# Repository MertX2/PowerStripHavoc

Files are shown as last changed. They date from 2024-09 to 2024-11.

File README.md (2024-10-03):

# PowerStripHavoc
PowerStripHavoc is a WIP power regulation PCB for Wii Portables that sits on top of the Wii mainboard and inbetween the CPU and GPU. It is heavily inspired by YveltalGriffin's [Thundervolt](https://github.com/mackieks/thundervolt) , loopj's [short stack](https://github.com/loopj/short-stack) project and different PCBs, and the [RVL-PMS](https://github.com/Gmanmodz/RVL-Power-Management-System) by gmanmodz. 

Its name is a combination of loopj's PowerStrip, which is the base of this project, and the Havoc weapon from Apex Legends. 

This Project is currently in the testing phases and is in no way ready to be used.




# Firmware
The firmware is written in Cpp using the Arduino Framework via [megaTinyCore](https://github.com/SpenceKonde/megaTinyCore) .
In order to compile it, you just need VSCode with the PlatformIO addon installed.

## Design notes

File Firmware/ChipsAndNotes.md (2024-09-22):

- IP2721 ODER CH224K
- CH224K Example Project https://hackaday.io/project/194207-usb-power-delivery-decoy-ch224k
- BQ driver, 2 Versionen, Spencer ist original, Ratti ist ein Fork für den BQ25896
- BQ driver selber implementieren SOLLTE einfach sein
- Evtl. RVLOADER pms spoofing???

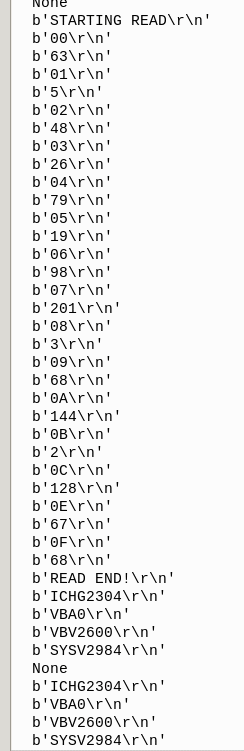
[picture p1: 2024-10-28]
Firmware/SerialRead_html_a3b800cb49ea278a.gif

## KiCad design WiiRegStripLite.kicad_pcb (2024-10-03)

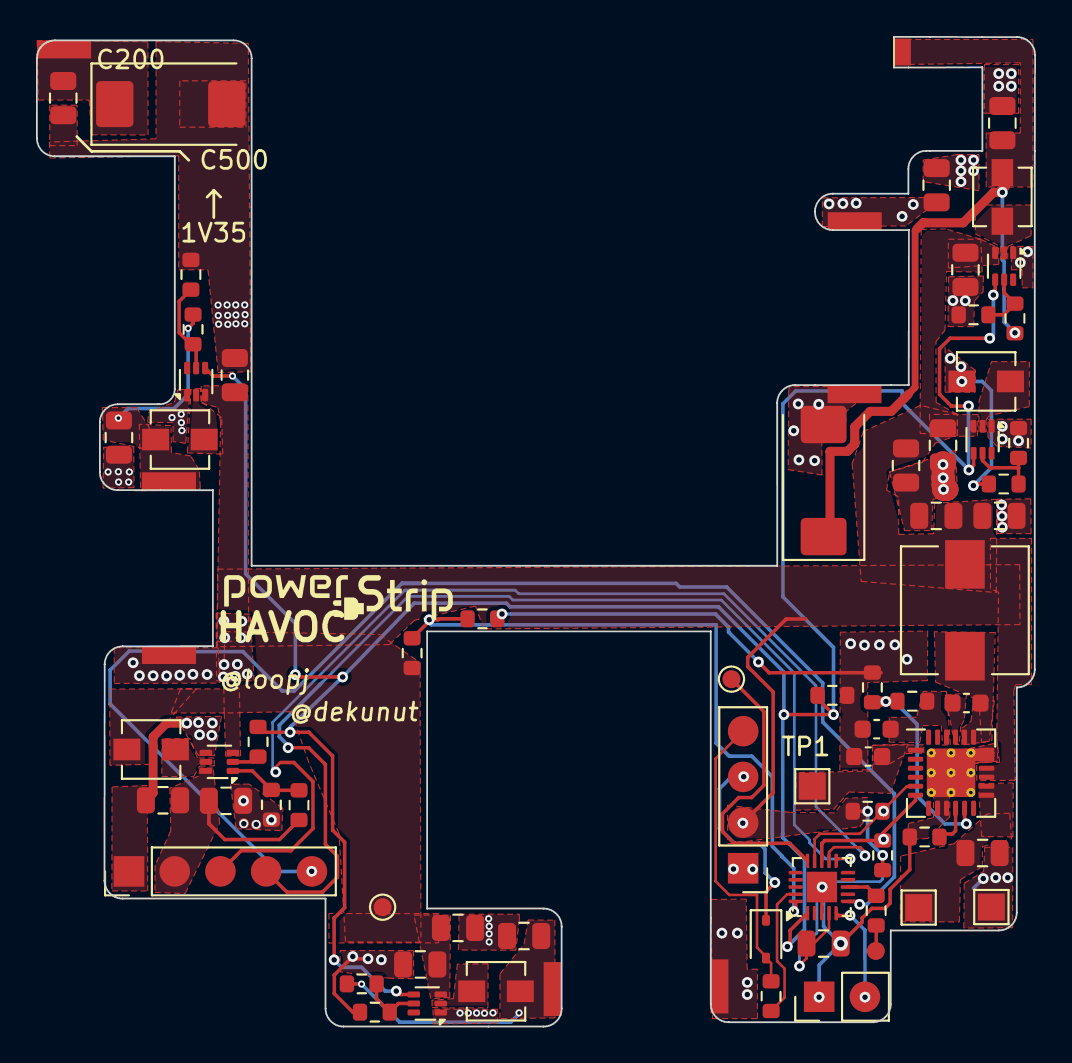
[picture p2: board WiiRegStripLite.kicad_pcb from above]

Board: 2 copper layers, 55.5 x 55.0 mm, 72 parts (0 on the bottom side), 39 nets.

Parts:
C1: 1uf; C_0603_1608Metric
C7: 0.047uf; C_0603_1608Metric
C11: 4.7uf; C_0603_1608Metric
C12, C13, C14, C14#2, C15, C26: 10uf; C_0805_2012Metric
C16, C17, C18, C19: 10uF; C_0805_2012Metric
C20, C21, C22, C23, C24, C25: 22uF; C_0805_2012Metric
C189: 220uF; CP_EIA-7343-20_Kemet-V
C200: 11uF; C_0805_2012Metric
C500: 150uF; CP_EIA-7343-20_Kemet-V
D1: B5819W; D_SOD-323
GND: BAT+; TestPoint_Pad_1.5x1.5mm
J1: Conn_01x04_Socket; PinHeader_1x04_P2.54mm_Vertical
J2: Conn_01x04_Socket; PinHeader_1x05_P2.54mm_Vertical
J3: Fan; PinHeader_1x02_P2.54mm_Vertical
L5: 2.2uh; L_Wuerth_HCI-7030
L6, L7, L8, L9, L10: 1uH; L_Vishay_IHLP-1212
R1: 261; R_0603_1608Metric
R10, R11, R12, R13, R27, R28: 10k; R_0603_1608Metric
R14: 66.5K; R_0603_1608Metric
R15, R17, R19, R21: 100K; R_0603_1608Metric
R16: 80k; R_0603_1608Metric
R18: 414k; R_0603_1608Metric
R20: 470; R_0603_1608Metric
R22: 124k; R_0603_1608Metric
R23: 100; R_0603_1608Metric
R24: 732k; R_0603_1608Metric
R25, R26: 100k; R_0603_1608Metric
TH1: 10k; R_0603_1608Metric
TP1: CHRG; TestPoint_Pad_1.5x1.5mm
TP2: BAT+; TestPoint_Pad_1.5x1.5mm
TP3, TP60: TestPoint; TestPoint_Pad_D1.0mm
TP4: U10; TestPoint_Pad_D1.0mm
TP5, TP7: GND; TestPoint_Pad_3x1.0mm
TP10: 3V3; TestPoint_Pad_1.5x1.0mm
TP20: 1V8; TestPoint_Pad_3x1.0mm
TP30: 1V15; TestPoint_Pad_3x1.0mm
TP40: 1V0; TestPoint_Pad_3x1.0mm
U5: BQ25895RTW; BQ25895
U6: ATtiny1616-M; VQFN-20-1EP_3x3mm_P0.4mm_EP1.7x1.7mm
U7, U8, U9, U10: TLV62585DRL; SOT-563
U11: TPS61023DRLR; SOT-563

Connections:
1V: C20.1, L6.2, R14.1, TP40.1
1V08: C21.1, L7.2, R16.1, TP30.1
1V35: C22.1, C200.1, C500.1, L8.2, R22.1, TP20.1
3V: C23.1, C189.1, L9.2, R18.1, TP10.1
5V: C24.1, C25.1, J2.2, R24.1, U11.6 (VOUT)
/Inductor3vIn: L9.1, U10.2 (SW)
/L1v: L6.1, U7.2 (SW)
/L1v08: L7.1, U8.2 (SW)
/L1v35: L8.1, U9.2 (SW)
/L5v: L10.1, U11.5 (SW)
/LBQ: C7.2, L5.2, U5.19 (SW), U5.20 (SW)
BTN: J2.5, U6.6 (PA5)
EN: R26.2, R28.2, U6.1 (PA2), U7.4 (EN), U8.4 (EN), U9.4 (EN), U10.4 (EN)
GND: C1.1, C11.2, C12.2, C13.1, C14.1, C14#2.1, C15.1, C16.2, C17.2, C18.2, C19.2, C20.2, C21.2, C22.2, C23.2, C24.2, C25.2, C26.1, C189.2, C200.2, C500.2, GND.1, J1.1, J2.1, J3.1, R1.1, R11.1, R15.2, R17.2, R19.2, R21.2, R25.2, R28.1, TH1.2, TP5.1, TP7.1, U5.8 (OTG), U5.9 (~CE), U5.17 (PGND), U5.18 (PGND), U5.25 (PGND), U6.3 (GND), U6.21 (GND), U7.1 (GND), U8.1 (GND), U9.1 (GND), U10.1 (GND), U11.4 (GND)
NeoPixelDIN: R23.1, TP60.1
unnamed: C12.1, TP2.1, U5.13 (BAT), U5.14 (BAT)
unnamed: D1.2 (A), J1.4, R20.1
unnamed: D1.1 (K), J1.3
unnamed: C7.1, U5.21 (BTST)
unnamed: R1.2, U5.10 (ILIM)
unnamed: C11.1, R10.2, U5.22 (REGN)
unnamed: R10.1, R11.2, U5.11 (TS)
unnamed: C1.2, TP1.1, U5.1 (VBUS)
unnamed: R14.2, R15.1, U7.5 (FB)
unnamed: R16.2, R17.1, U8.5 (FB)
unnamed: R19.1, R22.2, U9.5 (FB)
unnamed: R18.2, R21.1, U10.5 (FB)
unnamed: R26.1, U11.2 (EN)
unnamed: R24.2, R25.1, U11.1 (FB)
PA1: R27.1, TH1.1, U6.20 (PA1)
PA4: J3.2, U6.5 (PA4)
PA7: R23.2, U6.8 (PA7)
PC0: TP4.1, U6.15 (PC0)
RX: J2.4, U6.11 (PB3)
SCL: R13.2, U5.5 (SCL), U6.14 (PB0)
SDA: R12.1, U5.6 (SDA), U6.13 (PB1)
TX: J2.3, U6.12 (PB2)
UPDI: R20.2, U6.19 (~RESET/PA0)
VIN: C13.2, C14.2, C14#2.2, C15.2, C16.1, C17.1, C18.1, C19.1, C26.2, J1.2, L5.1, L10.2, R12.2, R13.1, R27.2, TP3.1, U5.15 (SYS), U5.16 (SYS), U6.4 (VCC), U7.3 (VIN), U8.3 (VIN), U9.3 (VIN), U10.3 (VIN), U11.3 (VIN)

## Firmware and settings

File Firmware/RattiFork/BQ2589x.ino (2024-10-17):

/*                                                     https://oshwlab.com/ratti3
  _|_|_|                _|      _|      _|  _|_|_|     https://youtube.com/@Ratti3
  _|    _|    _|_|_|  _|_|_|_|_|_|_|_|            _|   https://projecthub.arduino.cc/Ratti3
  _|_|_|    _|    _|    _|      _|      _|    _|_|     https://ratti3.blogspot.com
  _|    _|  _|    _|    _|      _|      _|        _|   https://hackaday.io/Ratti3
  _|    _|    _|_|_|      _|_|    _|_|  _|  _|_|_|     https://www.hackster.io/Ratti3
                                                       https://github.com/Ratti3

This file is part of https://github.com/Ratti3/BQ2589x-ATMEGA32U4-Charger-Powerbank-with-SSD1306-OLED
NTC code is from https://learn.adafruit.com/thermistor/using-a-thermistor

BQ2589x-ATMEGA32U4-Charger-Powerbank-with-SSD1306-OLED is free software: you can redistribute it and/or modify it under the terms of the 
GNU General Public License as published by the Free Software Foundation, either version 3 of the License, or (at your option) any later version.
BQ2589x-ATMEGA32U4-Charger-Powerbank-with-SSD1306-OLED is distributed in the hope that it will be useful, but WITHOUT ANY WARRANTY; 
without even the implied warranty of MERCHANTABILITY or FITNESS FOR A PARTICULAR PURPOSE. See the GNU General Public License for more details.
You should have received a copy of the GNU General Public License along with BQ2589x-ATMEGA32U4-Charger-Powerbank-with-SSD1306-OLED. If not, see <https://www.gnu.org/licenses/>.
    ____________
  -|            |-  A0 : TH_IC   [AI]         NTC for monitoring temperature close to the IC
  -|            |-  A2 : OTG     [DI]         Boost mode enable pin. The boost mode is activated when OTG_CONFIG = 1, OTG pin is high, and no input source is detected at VBUS.
  -|            |-  A3 : CE      [DI]         Active low Charge Enable pin. Battery charging is enabled when CHG_CONFIG = 1 and CE pin = Low. CE pin must be pulled High or Low.
  -|            |-  A4 : ENCA    [DI]         Rotary Encoder
  -|            |-  A5 : ENCB    [DI]         Rotary Encoder
  -| ATMEGA32U4 |-  ~5 : BUZ     [AO][PWM]    Buzzer
  -|            |-   7 : SW1     [DI][INT.6]  Rotary Encoder Switch, used to wake up from sleep mode.
  -|            |-  ~9 : INT     [DO][PCINT5] Open-drain Interrupt Output. The INT pin sends active low, 256-μs pulse to host to report charger device status and fault.
  -|            |- ~10 : PSEL    [DI]         Power source selection input. High indicates a USB host source and Low indicates an adapter source.
  -|            |- ~11 : WS2812  [DO]         WS2812B LEDs
  -|____________|- ~13 : D13_LED [DO]         LED_BUILTIN
  [DI] = Digital In, [DO] = Digital Out, [AI] = Analog In, [AO] = Analog Out
*/

// Current size of this code on the ATMEGA32U4 (SparkFun Pro Micro)
// Sketch uses 28536 bytes (99%) of program storage space. Maximum is 28672 bytes.
// Global variables use 1105 bytes (43%) of dynamic memory, leaving 1455 bytes for local variables. Maximum is 2560 bytes.

// Libraries
#include <Wire.h>
#include <EEPROM.h>            // v2.0    | https://github.com/PaulStoffregen/EEPROM
#include <BQ2589x.h>           // v1.0    | https://github.com/Ratti3/BQ2589x
#include <FastLED.h>           // v3.5.0  | https://github.com/FastLED/FastLED
#include <TimerOne.h>          // v1.1.1  | https://github.com/PaulStoffregen/TimerOne
#include <LowPower.h>          // v2.2    | https://github.com/LowPowerLab/LowPower
#include <AbleButtons.h>       // v0.3.0  | https://github.com/jsware/able-buttons
#include <BasicEncoder.h>      // v1.1.4  | https://github.com/micromouseonline/BasicEncoder
#include <Adafruit_GFX.h>      // v1.11.5 | https://github.com/adafruit/Adafruit-GFX-Library
#include <Adafruit_SSD1306.h>  // v2.5.7  | https://github.com/adafruit/Adafruit_SSD1306 (this needs to be modified to remove the splash screen otherwise it will not fit the ATMEGA32U4 flash)

// BQ25896
#define PIN_OTG A2         // BQ25896 OTG Digital Input
#define PIN_CE A3          // BQ25896 CE Digital Input
#define PIN_INT 9          // BQ25896 INT Digital Input
#define PIN_PSEL 10        // BQ25896 PSEL Digital Input
#define BQ2589x_ADDR 0x6B  // BQ25896 I2C Address
#define STOREVOLTAGE 3750  // VCHG Voltage for storage
bq2589x CHARGER;

// EEPROM save location, saved as byte
#define E_SAVE 0       // 0-1 - Settings saved state
#define E_VCHG 10      // arrPositionVCHG
#define E_ICHG 20      // arrPositionICHG
#define E_VOTG 30      // arrPositionVOTG
#define E_IOTG 40      // arrPositionIOTG
#define E_ROTATE 50    // oledRotation
#define E_SLEEP 60     // arraySleep
#define E_LED_BR 70    // arrPositionLED
#define E_PWR_DOWN 80  // pwrDown

// Value ranges for settings
int arrVCHG[4] = { 3840, 4096, 4192, 4208 };             // Charge voltage values (first one is used to set the STOREVOLTAGE, it is the minimum allowed value)
byte arrPositionVCHG = 2;                                // Set default charge voltage to 4.192V
int arrICHG[6] = { 512, 1024, 1536, 2048, 2560, 3072 };  // Charge current values
byte arrPositionICHG = 5;                                // Set default charge current to 3A
int arrVOTG[3] = { 4998, 5062, 5126 };                   // Boost voltage values
byte arrPositionVOTG = 1;                                // Set default boost voltage to 5.062V
int arrIOTG[5] = { 500, 750, 1200, 1650, 2150 };         // Boost current values
byte arrPositionIOTG = 4;                                // Set default boost current to 2.15A
byte oledRotation = 2;                                   // OLED default rotation setting
int arraySleep[3] = { 60, 120, 300 };                    // Sleep/Ship Mode timeout values in seconds
byte arrPositionSleep = 0;                               // Default Sleep/Ship Mode value
int arrayLED[4] = { 5, 10, 15, 20 };                     // LED brightness values
byte arrPositionLED = 0;                                 // Default LED brightness
bool pwrDOWN = 0;                                        // Enable/Disable Ship Mode

// Version number and boot text
#define TEXT1 "BQ25896"
#define TEXT2 "Battery Charger"
#define TEXT3 "Ratti3 Tech Corp"
#define VERSION "v1.0"

// AbleButtons
#define PIN_ENCODER_SW 7                 // SW1 PIN
using Button = AblePullupClickerButton;  // Button type
Button SW1(PIN_ENCODER_SW);              // The button to check is on pin

// FastLED
#define PIN_WS2812 11  // WS2812B Data PIN
#define NUM_LEDS 2     // Number of WS2812B LEDs
CRGB leds[NUM_LEDS];   // Set number of LEDs
bool stateLED0 = 0;    // Track state of LEDs

// OLED
#define OLED_ADDRESS 0x3C                   // OLED Address
Adafruit_SSD1306 OLED(128, 64, &Wire, -1);  // Adafruit OLED Class
unsigned int oledSLEEP = 0;                 // Counter for turning OLED off
unsigned long last_change = 0;              // Counter for turning OLED off
unsigned long now = 0;                      // Counter for turning OLED off

// Rotary Encoder, Timer & Menu
#define PIN_ENCA A4                                 // Rotary Encoder PIN A
#define PIN_ENCB A5                                 // Rotary Encoder PIN B
BasicEncoder ENCODER(PIN_ENCA, PIN_ENCB, HIGH, 2);  // BasicEncoder Class
int encoderPrev = 0;                                // Holds the encoder turns
bool menuMode = 0;                                  // Default menu mode
int menuPosition = 0;                               // Default menu position
bool justWokeUp = 0;                                // Track state of sleep/wake
#define MAINMENUITEMS 2                             // Number of selectable items in the main menu (count from 0)
#define SETUPMENUITEMS 8                            // Number of selectable items in the setup menu (count from 0)

// IC NTC Thermistor
#define PIN_THERMISTOR A0        // NTC Thermistor PIN
#define THERMISTORNOMINAL 10000  // NTC Thermistor nominal resistance
#define TEMPERATURENOMINAL 25    // NTC Thermistor nominal temperature
#define NUMSAMPLES 5             // Number of temperature samples to take
#define BCOEFFICIENT 3425        // NTC Thermistor B Coefficient
#define SERIESRESISTOR 10000     // NTC Thermistor series resistor
int samples[NUMSAMPLES];         // Store NTC samples

// Buzzer
#define PIN_BUZZER 5  // Buzzer PIN

void setup() {
  // Wait for things to warm up
  delay(1000);

  // I2C
  Wire.begin();

  // D13 LED
  pinMode(LED_BUILTIN, OUTPUT);
  digitalWrite(LED_BUILTIN, LOW);

  // AbleButtons setup
  pinMode(PIN_ENCODER_SW, INPUT);
  SW1.begin();

  // FastLED setup
  FastLED.addLeds<WS2812, PIN_WS2812, GRB>(leds, NUM_LEDS);
  FastLED.setBrightness(arrayLED[arrPositionLED]);

  // OLED setup
  OLED.begin(SSD1306_SWITCHCAPVCC, OLED_ADDRESS);
  OLED.setTextSize(1);
  OLED.setTextColor(SSD1306_WHITE);

  // Timer1 setup
  Timer1.initialize(1000);
  Timer1.attachInterrupt(timer_service);
  ENCODER.set_reverse();

  // BQ25896 setup
  // INT PIN Setup
  pinMode(PIN_INT, INPUT);
  // OTG [LOW = Off, HIGH = Boost]
  pinMode(PIN_OTG, OUTPUT);
  digitalWrite(PIN_OTG, HIGH);
  // CE [LOW = Charge, HIGH = Idle]
  pinMode(PIN_CE, OUTPUT);
  digitalWrite(PIN_CE, LOW);
  // PSEL [LOW = Adapter, HIGH = USB]
  pinMode(PIN_PSEL, OUTPUT);
  digitalWrite(PIN_PSEL, LOW);
  CHARGER.begin(&Wire, BQ2589x_ADDR);
  CHARGER.disable_watchdog_timer();
  CHARGER.adc_start(0);
  CHARGER.disable_charger();

  // Load (save defaults) EEPROM values
  loadEEPROM();

  // Display version on boot up
  setupDisplay();
}

void loop() {
  // Check for SW1 (Encoder Switch) presses
  SW1.handle();

  // Detect SW1 press using AbleButtons
  if (SW1.resetClicked()) {
    oledSLEEP = 0;
    OLED.dim(0);
    OLED.ssd1306_command(SSD1306_DISPLAYON);
    buttonPressed();
  }

  // Check for Encoder turns
  if (ENCODER.get_change()) {
    oledSLEEP = 0;
    OLED.dim(0);
    OLED.ssd1306_command(SSD1306_DISPLAYON);
    beepBOP(6000, 100);
    menuOption(ENCODER.get_count());
  }

  now = millis();

  unsigned int aSleep = arraySleep[arrPositionSleep];
  if (now - last_change > 1000 && oledSLEEP <= aSleep) {
    last_change = now;
    oledSLEEP++;
    if (menuMode) {
      displaySetupMenu();
    } else {
      displayStatus();
    }
    ledControl();
  } else if (oledSLEEP > aSleep && (CHARGER.is_charge_enabled() || CHARGER.is_otg_enabled())) {
    if (now - last_change > 1000) {
      last_change = now;
      ledControl();
    }
    OLED.dim(1);
    OLED.ssd1306_command(SSD1306_DISPLAYOFF);
  } else if (oledSLEEP > aSleep) {
    // If Ship Mode is enabled and timer has elasped, do a full power off
    if (pwrDOWN) {
      leds[0] = CRGB::Black;
      leds[1] = CRGB::Black;
      FastLED.show();
      CHARGER.enter_ship_mode();
    }

    // If timer for OLED display on time has expired, set the OLED contrast to 0m turn off OLED and power down the ATMEGA32U4
    OLED.dim(1);
    OLED.ssd1306_command(SSD1306_DISPLAYOFF);

    // Allow wake up pin to trigger interrupt on low.
    attachInterrupt(digitalPinToInterrupt(PIN_ENCODER_SW), wakeUp, 0);

    // Put the ATMEGA32U4 to sleep
    LowPower.powerDown(SLEEP_FOREVER, ADC_OFF, BOD_OFF);

    // Disable external pin interrupt on wake up pin.
    detachInterrupt(digitalPinToInterrupt(PIN_ENCODER_SW));

    // Wake up the OLED
    OLED.dim(0);
    OLED.ssd1306_command(SSD1306_DISPLAYON);
    // Reset the OLED sleep timer
    oledSLEEP = 0;
  }
}

// Sleep state tracking
void wakeUp() {
  justWokeUp = 1;
  beepBOP(3000, 300);
}

// Used to check encoder turns using the TimerOne service
void timer_service() {
  ENCODER.service();
}

// Default Status Display
void displayStatus() {
  OLED.clearDisplay();
  // VBUS input status
  OLED.setCursor(0, 0);
  OLED.print(" INPUT:");
  OLED.println(CHARGER.get_vbus_type_text());
  // Charge status
  OLED.setCursor(0, 10);
  OLED.print("CHARGE:");
  OLED.println(CHARGER.get_charging_status_text());
  OLED.drawLine(1, 20, 126, 20, SSD1306_WHITE);
  // VBUS Voltage
  OLED.setCursor(0, 23);
  OLED.print("VBUS:");
  OLED.println(float(CHARGER.adc_read_vbus_volt() * 0.001), 3);
  // VSYS Voltage
  OLED.setCursor(68, 23);
  OLED.print("VSYS:");
  OLED.println(float(CHARGER.adc_read_sys_volt() * 0.001), 3);
  // VBAT Voltage
  OLED.setCursor(0, 33);
  OLED.print("VBAT:");
  OLED.println(float(CHARGER.adc_read_battery_volt() * 0.001), 3);
  // Charge Current
  OLED.setCursor(68, 33);
  OLED.print("ICHG:");
  OLED.println(float(CHARGER.adc_read_charge_current() * 0.001), 3);
  // IC Temp
  OLED.setCursor(0, 43);
  OLED.print("IC");
  OLED.print(char(247));
  OLED.print("C:");
  OLED.println(ntcIC(), 1);
  // IDPM
  OLED.setCursor(68, 43);
  OLED.print("IDPM:");
  OLED.println(float(CHARGER.read_idpm_limit() * 0.001), 2);
  // Options
  OLED.drawLine(1, 53, 126, 53, SSD1306_WHITE);
  OLED.setCursor(7, 56);
  if (CHARGER.is_charge_enabled()) {
    OLED.print("STOP");
  } else {
    OLED.print("CHARGE");
  }
  OLED.setCursor(61, 56);
  if (CHARGER.is_otg_enabled()) {
    OLED.print("STOP");
  } else {
    OLED.print("OTG");
  }
  OLED.setCursor(97, 56);
  OLED.print("SETUP");

  // Set cursor position for the > selector on the main menu
  byte X = 0;
  byte Y = 0;
  switch (menuPosition) {
    case 0:
      X = 0;
      Y = 56;
      break;
    case 1:
      X = 54;
      Y = 56;
      break;
    case 2:
      X = 90;
      Y = 56;
      break;
  }
  OLED.setCursor(X, Y);
  OLED.print(">");
  OLED.display();
}

// Runs when the encoder is turned
void menuOption(int encoderCurr) {
  // Set the max number of menu items starting from 0
  int menuMax = 0;
  if (menuMode == 0) {
    menuMax = MAINMENUITEMS;
  } else {
    menuMax = SETUPMENUITEMS;
  }

  // Calculate the cursor position for the menus
  if (encoderCurr < encoderPrev) {
    --menuPosition;
    if (menuPosition < 0) menuPosition = menuMax;
  } else if (encoderCurr > encoderPrev) {
    ++menuPosition;
    if (menuPosition > menuMax) menuPosition = 0;
  }
  encoderPrev = encoderCurr;
}

// The event handler for the button.
void buttonPressed() {
  // Set error state
  bool errorBeep = 0;

  // Prevent encoder action if waking up
  if (justWokeUp) {
    justWokeUp = 0;
    return;
  }

  // Setup Menu
  if (menuMode) {
    switch (menuPosition) {
      case 0:  // Set Charge Voltage
        ++arrPositionVCHG;
        if (arrPositionVCHG > 3) arrPositionVCHG = 0;
        setChargeVoltage(arrPositionVCHG);
        break;
      case 1:  // Set Charge Current
        ++arrPositionICHG;
        if (arrPositionICHG > 5) arrPositionICHG = 0;
        setChargeCurrent(arrPositionICHG);
        break;
      case 2:  // Set Boost Voltage
        ++arrPositionVOTG;
        if (arrPositionVOTG > 2) arrPositionVOTG = 0;
        setOTGVoltage(arrPositionVOTG);
        break;
      case 3:  // Set Boost Current
        ++arrPositionIOTG;
        if (arrPositionIOTG > 4) arrPositionIOTG = 0;
        setOTGCurrent(arrPositionIOTG);
        break;
      case 4:  // Set OLED Rotation
        if (oledRotation == 2) {
          oledRotation = 0;
        } else {
          oledRotation = 2;
        }
        OLED.setRotation(oledRotation);
        break;
      case 5:  // Set Sleep Timer
        ++arrPositionSleep;
        if (arrPositionSleep > 2) arrPositionSleep = 0;
        break;
      case 6:  // Set LED brightness
        ++arrPositionLED;
        if (arrPositionLED > 3) arrPositionLED = 0;
        FastLED.setBrightness(arrayLED[arrPositionLED]);
        break;
      case 7:  // Toggle Ship Mode (full power down)
        pwrDOWN = !pwrDOWN;
        break;
      case 8:  // Exit Setup Menu and save settings to EEPROM
        saveEEPROM();
        menuMode = 0;
        menuPosition = 0;
        break;
    }
  } else {
    if (menuPosition == 0) {
      // Enable/disable charger, can only be enabled if there is and external power supply
      if (CHARGER.is_charge_enabled()) {
        CHARGER.disable_charger();
      } else if (CHARGER.get_vbus_type() > 0 && CHARGER.get_vbus_type() < 7) {
        CHARGER.enable_charger();
      } else {
        errorBeep = 1;
      }
    } else if (menuPosition == 1) {
      // Enable/Disable OTG, only can be enabled if there is a battery and there is no external power source
      if (CHARGER.is_otg_enabled()) {
        CHARGER.disable_otg();
      } else if (CHARGER.get_vbus_type() == 0) {
        CHARGER.enable_otg();
      } else {
        errorBeep = 1;
      }
    } else if (menuPosition == 2) {
      // Display the Setup Menu
      menuMode = 1;
      menuPosition = 0;
      displaySetupMenu();
    }
  }

  // Play an error beep if errorBeep == True
  if (errorBeep) {
    beepBOP(4000, 100);
    delay(100);
    beepBOP(2000, 100);
  } else {
    beepBOP(4000, 100);
  }
}

// Show the setup menu
void displaySetupMenu() {
  OLED.clearDisplay();
  OLED.setCursor(51, 0);
  OLED.println("SETUP");
  OLED.drawLine(1, 9, 126, 9, SSD1306_WHITE);
  OLED.setCursor(0, 13);
  OLED.print("CHG:  ");
  if (arrPositionVCHG == 0) {
    OLED.print("STORE   ");
  } else {
    OLED.print(float(CHARGER.get_charge_voltage() * 0.001), 3);
    OLED.print("V  ");
  }
  OLED.print(float(CHARGER.get_charge_current() * 0.001), 3);
  OLED.println("A");
  OLED.setCursor(0, 23);
  OLED.print("OTG:  ");
  OLED.print(float(CHARGER.get_otg_voltage() * 0.001), 3);
  OLED.print("V  ");
  OLED.print(float(CHARGER.get_otg_current() * 0.001), 3);
  OLED.println("A");
  OLED.setCursor(0, 33);
  OLED.print("ROT:  ");
  if (oledRotation == 0) {
    OLED.print("  0");
  } else {
    OLED.print("180");
  }
  OLED.print(char(247));
  OLED.print("  SLP:  ");
  OLED.println(arraySleep[arrPositionSleep]);
  OLED.setCursor(0, 43);
  OLED.print("LED:  ");
  byte LED = 0;
  if (arrPositionLED == 0) {
    LED = 25;
  } else if (arrPositionLED == 1) {
    LED = 50;
  } else if (arrPositionLED == 2) {
    LED = 75;
  } else {
    LED = 100;
  }
  OLED.print(LED);
  OLED.print("%  ");
  OLED.setCursor(72, 43);
  OLED.print("APO:  ");
  if (pwrDOWN) {
    OLED.println("ON");
  } else {
    OLED.println("OFF");
  }
  OLED.drawLine(1, 52, 126, 52, SSD1306_WHITE);
  OLED.setCursor(53, 57);
  OLED.print("SAVE");

  // Set the position of the > cursor
  byte X = 0;
  byte Y = 0;
  switch (menuPosition) {
    case 0:  // VCHG
      X = 29;
      Y = 13;
      break;
    case 1:  // ICHG
      X = 77;
      Y = 13;
      break;
    case 2:  // VOTG
      X = 29;
      Y = 23;
      break;
    case 3:  // IOTG
      X = 77;
      Y = 23;
      break;
    case 4:  // OLED Rotation
      X = 29;
      Y = 33;
      break;
    case 5:  // Sleep Timer
      X = 101;
      Y = 33;
      break;
    case 6:  // LED Brightness
      X = 29;
      Y = 43;
      break;
    case 7:  // Ship Mode
      X = 101;
      Y = 43;
      break;
    case 8:  // Exit to main screen
      X = 46;
      Y = 57;
      break;
  }
  OLED.setCursor(X, Y);
  OLED.print(">");
  OLED.display();
}

// Set the battery charge voltage
void setChargeVoltage(int volt) {
  CHARGER.set_charge_voltage(arrVCHG[volt]);
}

// Set the battery charge current
void setChargeCurrent(int curr) {
  CHARGER.set_charge_current(arrICHG[curr]);
}

// Set the OTG voltage
void setOTGVoltage(int volt) {
  CHARGER.set_otg_voltage(arrVOTG[volt]);
}

// Set the OTG current
void setOTGCurrent(int curr) {
  CHARGER.set_otg_current(arrIOTG[curr]);
}

// Calculate the temperature of the NTC mounted next to the BQ25896
float ntcIC() {
  uint8_t i;
  float average;

  // take N samples in a row, with a slight delay
  for (i = 0; i < NUMSAMPLES; i++) {
    samples[i] = analogRead(PIN_THERMISTOR);
    delay(10);
  }

  // average all the samples out
  average = 0;
  for (i = 0; i < NUMSAMPLES; i++) {
    average += samples[i];
  }
  average /= NUMSAMPLES;

  // convert the value to resistance
  average = 1023 / average - 1;
  average = SERIESRESISTOR / average;

  float steinhart;
  steinhart = average / THERMISTORNOMINAL;           // (R/Ro)
  steinhart = log(steinhart);                        // ln(R/Ro)
  steinhart /= BCOEFFICIENT;                         // 1/B * ln(R/Ro)
  steinhart += 1.0 / (TEMPERATURENOMINAL + 273.15);  // + (1/To)
  steinhart = 1.0 / steinhart;                       // Invert
  steinhart -= 273.15;                               // convert absolute temp to C

  return steinhart;
}

// WS2812B LED control
void ledControl() {
  stateLED0 = !stateLED0;
  // Blink LEDs blue when OTG in on
  if (CHARGER.is_otg_enabled()) {
    if (stateLED0) {
      leds[0] = CRGB::Black;
    } else {
      leds[0] = CRGB::Blue;
    }
  } else { // Blink the LEDs depending on the charging status
    switch (CHARGER.get_charging_status()) {
      case 0:
        leds[0] = CRGB::Black;
        break;
      case 1:
        if (stateLED0) {
          leds[0] = CRGB::Black;
        } else {
          leds[0] = CRGB::Orange;
        }
        break;
      case 2:
        if (stateLED0) {
          leds[0] = CRGB::Black;
        } else {
          leds[0] = CRGB::Red;
        }
        break;
    }
  }

  // Call the charge detector function, will blink GREEN if STORAGE voltage has been reached
  detectCHG();

  FastLED.show();
}

// Detects charge voltage/current and disables charger if required
void detectCHG() {
  bool x = 0;
  // Determine if STORE mode is on, is charging and VBAT > 3.7V
  // Determine if no battery is connected
  // Check if charging  is finished
  if (CHARGER.is_charge_enabled() && CHARGER.adc_read_battery_volt() > STOREVOLTAGE && arrPositionVCHG == 0) {
    x = 1;
  } else if (CHARGER.is_charge_enabled() && CHARGER.adc_read_charge_current() < 100) {
    x = 1;
  } else if (CHARGER.get_charging_status() == 3) {
    x = 1;
  }

  // Disble charger based on previous calculations above
  if (x) {
    for (byte i = 0; i <= 3; i++) {
      beepBOP(2000, 100);
      delay(100);
      beepBOP(3000, 100);
      delay(100);
      beepBOP(4000, 100);
    }
    CHARGER.disable_charger();
  }
}
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

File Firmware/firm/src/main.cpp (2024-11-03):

#include <Arduino.h>
#include <Wire.h>
#include <tinyNeoPixel_Static.h>
#include <avr/sleep.h>
#include <bq.hpp>

#define DEBUG

#define BTN_PIN PIN_PA5
#define EN_PIN PIN_PA2
#define SDA_PIN 8
#define SCL_PIN 9
#define FAN_PIN PIN_PA4
#define NTC_PIN PIN_PA1
#define U10_PIN PIN_PB3

// KELVIN = 273.15

bool fanOn = 0;

//neopixel static uses less ressources, so less power??? see megatinycore extra docs
byte pixels[12];
tinyNeoPixel leds = tinyNeoPixel(4, PIN_PA7, NEO_GRB, pixels);

uint8_t batStat = 0;
bool cycle = 0;

void neoPixelTask() {
  switch (batStat)
  {
  case 6:
    if(cycle) {
      cycle = 0;
      leds.setPixelColor(0, 0, 255, 0);
      leds.show();
    }
    else {
      cycle = 1;
      leds.setPixelColor(0, 0, 0, 0);
      leds.show();
    }
    break;
  case 5:
    leds.setPixelColor(0, 0, 255, 0);
    leds.show();
    break;
  case 4:
    leds.setPixelColor(0, 127, 255, 0);
    leds.show();
    break;
  case 3:
    leds.setPixelColor(0, 255, 127, 0);
    leds.show();
    break;
  case 2:
    leds.setPixelColor(0, 255, 0, 0);
    leds.show();
    break;
  case 1:
    if(cycle) {
      cycle = 0;
      leds.setPixelColor(0, 255, 0, 0);
      leds.show();
    }
    else {
      cycle = 1;
      leds.setPixelColor(0, 0, 0, 0);
      leds.show();
    }
    break;
  default:
    break;
  }
}

uint32_t intermediate = 1023UL * 1500;

uint16_t readSupplyVoltage() { // returns value in millivolts to avoid floating point //NUR NÖTIG, WENN BQ VSYS SICH NICHT FESTLEGEN LÄSST !!!
    analogReference(VDD);
    VREF.CTRLA = VREF_ADC0REFSEL_1V5_gc;
    // there is a settling time between when reference is turned on, and when it becomes valid.
    // since the reference is normally turned on only when it is requested, this virtually guarantees
    // that the first reading will be garbage; subsequent readings taken immediately after will be fine.
    // VREF.CTRLB|=VREF_ADC0REFEN_bm;
    // delay(10);
    uint16_t reading = analogRead(ADC_INTREF); // Crumple the reading up into a ball and toss in the general direction of the trash.
    reading = analogRead(ADC_INTREF);          // Now we take the *real* reading.
    uint32_t intermediate = 1023UL * 1500;     // This would overflow a 16-bit variable.
    reading = intermediate / reading;          // Long division sucks! This single line takes about 600 clocks to execute!
    // And **this** is why the reference voltages on the 0/1-series parts suck! The comparable math on the 2-series takes maybe
    // 40 clocks, at most!
    return reading;
}

uint16_t getAnalogValue() {
 return ADC0.RES / 2; // return the most recent result on channel A
}

uint8_t getTemp() {
  uint16_t vdd = intermediate / readSupplyVoltage(); //NUR NÖTIG, WENN BQ VSYS SICH NICHT FESTLEGEN LÄSST !!!
  analogReference(INTERNAL2V5);

  uint16_t average = getAnalogValue();
  average = 1023 / average - 1;
  average = 10000 / average;

  float steinhart;
  steinhart = average / 10000;     // (R/Ro)
  steinhart = log(steinhart);                  // ln(R/Ro)
  steinhart /= 3380;                   // 1/B * ln(R/Ro)
  steinhart += 1.0 / (25 + 273.15); // + (1/To)
  steinhart = 1.0 / steinhart;                 // Invert
  return steinhart;    
}
//This will propably get axed.
void fanCheck() {
  if(getTemp() > 333) {
    if(fanOn == 0) {
      analogWrite(FAN_PIN, HIGH);
      fanOn = 1;
    }
  }
  else if(getTemp() < 320) {
    if(fanOn == 1) {
      analogWrite(FAN_PIN, LOW);
      fanOn = 0;
    }
  }
}

void readAllRegs() {
  Serial.println("STARTING READ");
  Serial.println("00");
  Serial.println(readRawReg(0x00));
  Serial.println("01");
  Serial.println(readRawReg(0x01));
  Serial.println("02");
  Serial.println(readRawReg(0x02));
  Serial.println("03");
  Serial.println(readRawReg(0x03));
  Serial.println("04");
  Serial.println(readRawReg(0x04));
  Serial.println("05");
  Serial.println(readRawReg(0x05));
  Serial.println("06");
  Serial.println(readRawReg(0x06));
  Serial.println("07");
  Serial.println(readRawReg(0x07));
  Serial.println("08");
  Serial.println(readRawReg(0x08));
  Serial.println("09");
  Serial.println(readRawReg(0x09));
  Serial.println("0A");
  Serial.println(readRawReg(0x0A));
  Serial.println("0B");
  Serial.println(readRawReg(0x0B));
  Serial.println("0C");
  Serial.println(readRawReg(0x0C));
  Serial.println("0E");
  Serial.println(readRawReg(0x0E));
  Serial.println("0F");
  Serial.println(readRawReg(0x0F));
  Serial.println("READ END!");
}
//Interrupt to wake the chip up from sleep whenever power button is pressed.
/*ISR(PORTA_PORT_vect)
{
  return;
}*/

//Button timing variable
unsigned long startMillis = 0;


void goToSleep();

void wakeSetup() {
  Serial.println("WK0");
  startMillis = millis();
  while(digitalReadFast(BTN_PIN) == LOW) {
    if(uint16_t(millis - startMillis) > 2000) {
      Serial.println("WK1");
      ADC0.CTRLA |= 1;
      digitalWriteFast(EN_PIN, HIGH);
      delay(150);
      digitalWriteFast(FAN_PIN, HIGH);
      //PORTA.PIN2CTRL = 0x08;
      //VPORTA.INTFLAGS = 255; 
      Serial.println("RT");
      return;
    }
  }
  goToSleep(); 
}

void goToSleep() {
  ADC0.CTRLA &= ~ADC_ENABLE_bm;
  PORTA.PIN2CTRL |= PORT_ISC_FALLING_gc;
  if(!regWriteCheck) {
    writeToAllRegs();
  }
  Serial.println("SLP");
  Serial.flush();
  delay(100);
  sleep_cpu();
  //wakeSetup();
}

void powerButtonCheck() {
  startMillis = millis();
  while(digitalReadFast(BTN_PIN) == LOW) {
    if(uint16_t(millis - startMillis) > 2000) {
        goToSleep();
    }
  }
  return;
}

void setup() {
  //Sleep mode
  set_sleep_mode(SLEEP_MODE_PWR_DOWN);
  sleep_enable();
  //ADC setup
  ADC0.MUXPOS = 0x01; //reads from PA1
  ADC0.CTRLA = ADC_ENABLE_bm|ADC_FREERUN_bm; //start in freerun
  ADC0.CTRLB = ADC_SAMPNUM_ACC2_gc;
  ADC0.COMMAND=ADC_STCONV_bm; //start first conversion!
  // Energysaving Measure, see megatinycore extra docs
  pinModeFast(PIN_PA3, OUTPUT);
  pinModeFast(PIN_PC1, OUTPUT);
  pinModeFast(PIN_PC2, OUTPUT);
  pinModeFast(PIN_PC3, OUTPUT);
  pinModeFast(PIN_PB4, OUTPUT);
  pinModeFast(PIN_PB5, OUTPUT);
  //Dont know why, just felt right :)
  turnOffPWM(PIN_PA3);
  turnOffPWM(PIN_PC1);
  turnOffPWM(PIN_PA5);
  //Neopixel pin
  pinModeFast(PIN_PA7, OUTPUT);
  //Rest of the pins
  pinModeFast(BTN_PIN, INPUT_PULLUP);
  pinModeFast(EN_PIN, OUTPUT);
  pinModeFast(FAN_PIN, OUTPUT);
  pinModeFast(NTC_PIN, INPUT);
  pinModeFast(U10_PIN, OUTPUT);
  //Serial and I2C init
  Serial.begin(9600);
  Wire.swap(0);
  Wire.begin();
  Wire.setClock(100000);
  //BQ Write
  Serial.println("SET");
  if(writeToAllRegs() == 0) {
    Serial.println("WERR");
    delay(100);
    Serial.println("WERR");
    delay(100);
    Serial.println("WERR");
    delay(100);
    Serial.println("WERR");
    delay(100);
    Serial.println("WERR");
  }
  //readAllRegs();
  attachInterrupt(digitalPinToInterrupt(BTN_PIN),wakeSetup,FALLING);
  goToSleep();
}




//Tasktimer.
unsigned long loopMillis = 0;
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

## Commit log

2024-09-08 Integrated Power Strip, working on regulators and bq
    [WiiRegStripLite.kicad_pcb, WiiRegStripLite.kicad_sch]
2024-09-08 More Reg Work, MCU placement
    [WiiRegStripLite.kicad_pcb]
2024-09-09 More work
    [WiiRegStripLite.kicad_pcb, WiiRegStripLite.kicad_sch]
2024-09-13 Final Design
    [WiiRegStripLite.kicad_pcb, WiiRegStripLite.kicad_sch]
2024-09-13 Gerber gen and new ibom
    [WiiRegStripLite-B_Cu.gbl, WiiRegStripLite-B_Mask.gbs, WiiRegStripLite-B_Paste.gbp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]
2024-09-14 More edits
    Rounded edges, moved traces, added EN pull down resistor
    [WiiRegStripLite-B_Cu.gbl, WiiRegStripLite-B_Mask.gbs, WiiRegStripLite-B_Paste.gbp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]
2024-09-25 Reg Setup BQ
    [WiiRegStripLite.kicad_pcb]
2024-09-28 A LOT of firmware work
    [WiiRegStripLite.kicad_sch]
2024-09-29 Firmware optimization
    Implemented sleep states, energy saving, adc register control, adc freerun mode, adc accumulation, interrupt service routines for waking from deep sleep,
    fancheck, powerbuttoncheck, working on batVoltage percentage calculator
2024-09-30 Final touches
    Implemented NeoPixelTask, implemented Battery levels, implemented different RegValueCalculations
2024-10-01 Some more work
    [WiiRegStripLite.kicad_pcb]
2024-10-03 Added U10 emulation on TX Pad of pcb
    [WiiRegStripLite.kicad_pcb]
2024-10-04 EN pin testing
2024-10-27 Fixed Master setting and added pin and clock defines
    [main.cpp]
2024-10-28 I2C Comms are working, now have to iron out the bugs.
    [main.cpp]
2024-11-02 Clean up and fixed the reg writes
    [bq.cpp, bq.hpp, main.cpp]
